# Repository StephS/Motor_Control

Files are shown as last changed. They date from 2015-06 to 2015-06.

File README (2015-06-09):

This board is an H-Bridge DC Motor Controller. The ratings are yet to be determined (requires calculation).
The end goal is to support a 12v 60A Electric Trolling Motor for a boat. This board does NOT have a PWM source (that will be a separate board).
Licence is CC-BY-SA

This board is a PROTOTYPE until the design is built and tested.

The bottom traces need Solid wire soldered on to improve current capacity. Please read the Allegro A3941 Datasheet for usage.

If you'd like to donate so I can buy the full version of Eagle, and make more cool stuff, please contact me through Google+

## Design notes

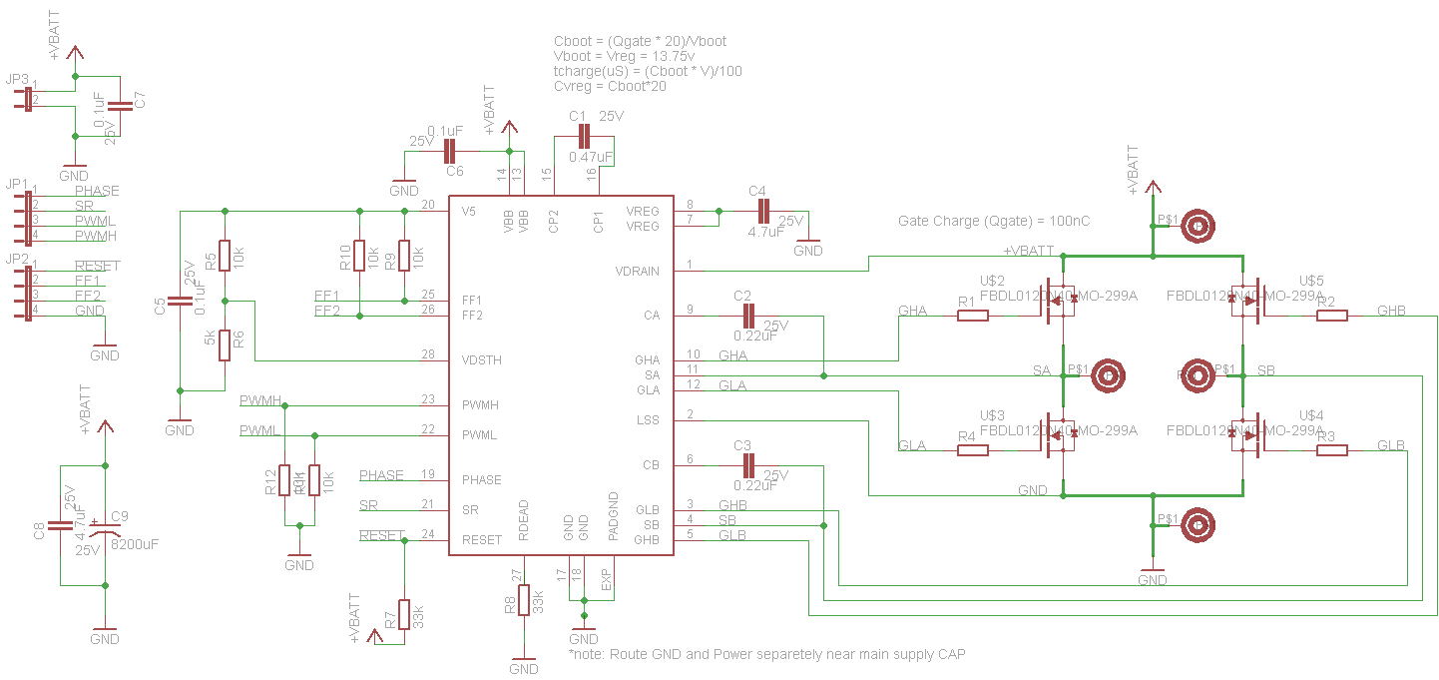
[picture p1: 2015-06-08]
Schematic.png

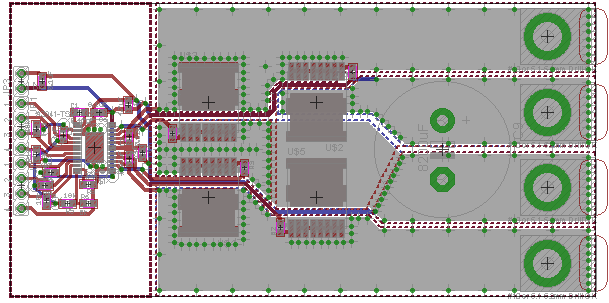
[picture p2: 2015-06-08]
Layout.png

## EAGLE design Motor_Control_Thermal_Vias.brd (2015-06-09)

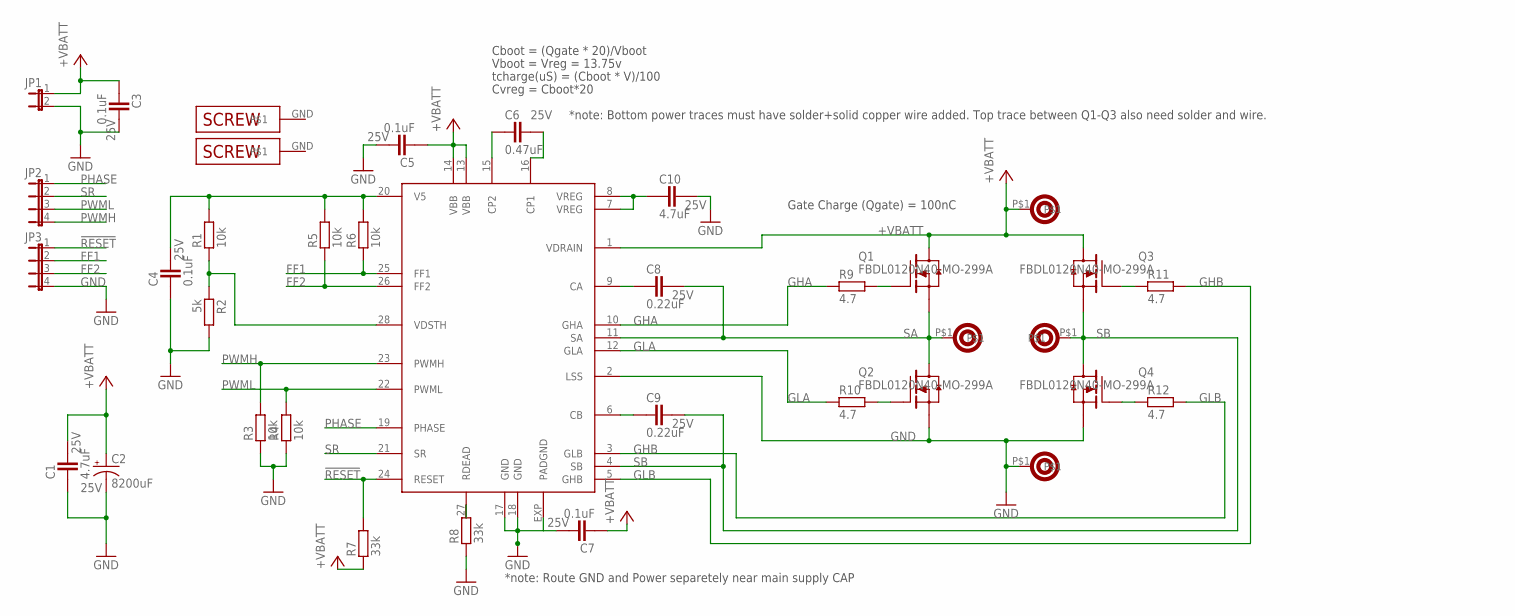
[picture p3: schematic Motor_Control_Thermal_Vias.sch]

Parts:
C1, C10: 4.7uF; CAPC1608X92N; VOLTAGE 25V
C2: 8200uF; CAP-10-22; VOLTAGE 25V
C3, C5, C7: 0.1uF; CAPC1608X92N; VOLTAGE 25V
C4: 0.1uF; CAPC_0603_LONG; VOLTAGE 25V
C6: 0.47uF; CAPC1608X92N; VOLTAGE 25V
C8, C9: 0.22uF; CAPC_0603_LONG; VOLTAGE 25V
J1, J2, J3, J4: 63971-1-QC_TAB-RA; QUICK_CONN_TAB-RA
JP1: JP1E; JP1
JP2, JP3: JP4E; JP4
Q1, Q2, Q3, Q4: FBDL0120N40-MO-299A; MO-299
R1, R3, R4, R5, R6: 10k; RESC1608X55N
R2: 5k; RESC1608X55N
R7, R8: 33k; RESC1608X55N
R9, R10, R11, R12: 4.7; RESC1608X55N
SCREW1, SCREW2: SCREW-4MM; PLATEDSCREW-4MM
U1: A3941-TSSOP28-LP; TSSOP28-LP

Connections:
!RESET: JP3.1, R7.2, U1.24 (RESET)
+VBATT: C1.2, C2.+, C3.1, C5.1, C7.1, J2.P$1, JP1.1, Q1.P$9 (D), Q3.P$9 (D), R7.1, U1.1 (VDRAIN), U1.13 (VBB), U1.14 (VBB)
FF1: JP3.2, R6.1, U1.25 (FF1)
FF2: JP3.3, R5.1, U1.26 (FF2)
GHA: R9.1, U1.10 (GHA)
GHB: R11.2, U1.5 (GHB)
GLA: R10.1, U1.12 (GLA)
GLB: R12.2, U1.3 (GLB)
GND: C1.1, C2.-, C3.2, C4.1, C5.2, C7.2, C10.2, J4.P$1, JP1.2, JP3.4, Q2.P$2 (S), Q2.P$3 (S), Q2.P$4 (S), Q2.P$5 (S), Q2.P$6 (S), Q2.P$7 (S), Q2.P$8 (S), Q4.P$2 (S), Q4.P$3 (S), Q4.P$4 (S), Q4.P$5 (S), Q4.P$6 (S), Q4.P$7 (S), Q4.P$8 (S), R2.2, R3.1, R4.1, R8.1, U1.2 (LSS), U1.17 (GND), U1.18 (GND), U1.EXP (PADGND)
unnamed: Q1.P$1 (G), R9.2
unnamed: Q2.P$1 (G), R10.2
unnamed: Q4.P$1 (G), R12.1
unnamed: Q3.P$1 (G), R11.1
unnamed: C10.1, U1.7 (VREG), U1.8 (VREG)
unnamed: C8.1, U1.9 (CA)
unnamed: R1.1, R2.1, U1.28 (VDSTH)
unnamed: C9.1, U1.6 (CB)
unnamed: R8.2, U1.27 (RDEAD)
unnamed: C6.1, U1.15 (CP2)
unnamed: C6.2, U1.16 (CP1)
PHASE: JP2.1, U1.19 (PHASE)
PWMH: JP2.4, R3.2, U1.23 (PWMH)
PWML: JP2.3, R4.2, U1.22 (PWML)
SA: C8.2, J1.P$1, Q1.P$2 (S), Q1.P$3 (S), Q1.P$4 (S), Q1.P$5 (S), Q1.P$6 (S), Q1.P$7 (S), Q1.P$8 (S), Q2.P$9 (D), U1.11 (SA)
SB: C9.2, J3.P$1, Q3.P$2 (S), Q3.P$3 (S), Q3.P$4 (S), Q3.P$5 (S), Q3.P$6 (S), Q3.P$7 (S), Q3.P$8 (S), Q4.P$9 (D), U1.4 (SB)
SR: JP2.2, U1.21 (SR)
V5: C4.2, R1.2, R5.2, R6.2, U1.20 (V5)

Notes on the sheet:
Cboot = (Qgate * 20)/Vboot
Vboot = Vreg = 13.75v
Gate Charge (Qgate) = 100nC
tcharge(uS) = (Cboot * V)/100
Cvreg = Cboot*20
*note: Route GND and Power separetely near main supply CAP
*note: Bottom power traces must have solder+solid copper wire added. Top trace between Q1-Q3 also need solder and wire.

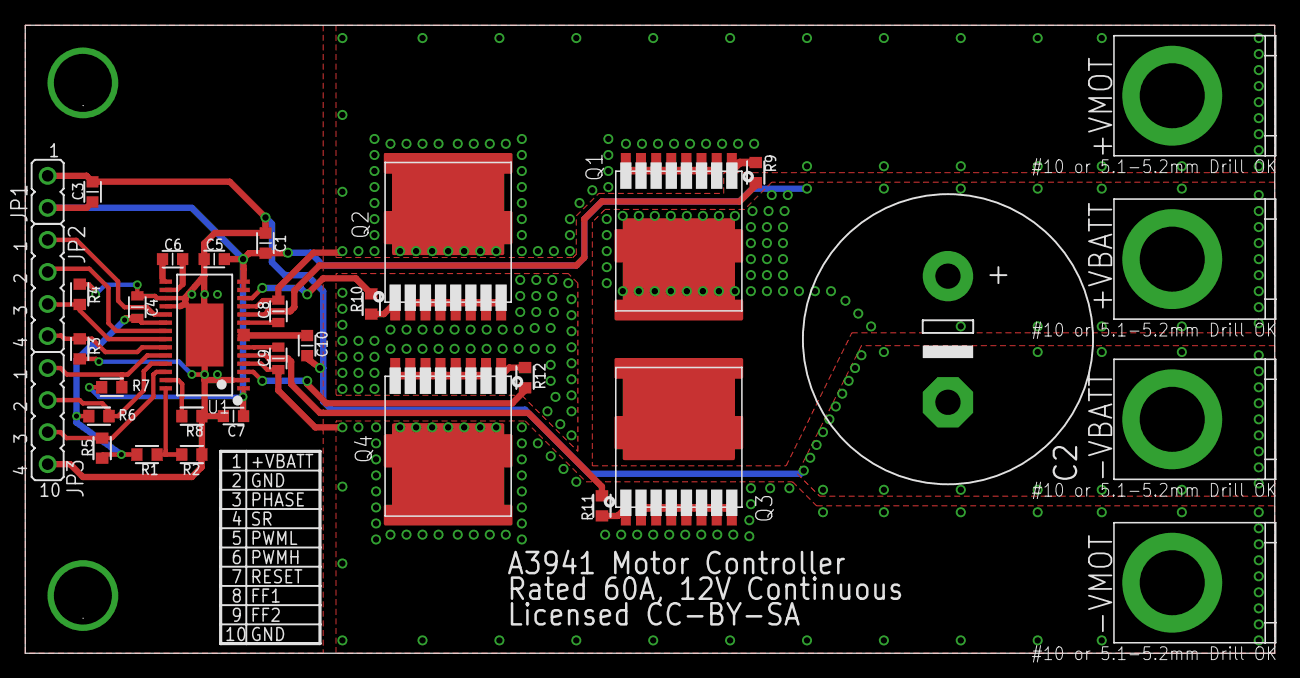
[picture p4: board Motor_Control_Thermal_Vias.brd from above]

Board: 2 copper layers, 99.1 x 49.8 mm, 36 parts (0 on the bottom side), 27 nets.

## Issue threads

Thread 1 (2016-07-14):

Board is tested?

xpix, 2016-07-14:
Hello,

i like your Design of this motor control. After a year i want to know, if the board tested know or it's just a design?

Frank

StephS, 2016-07-23:
Sorry, I have not tested it yet. No funds to make it.

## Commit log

2015-06-08 First board revision.
    The gate resistors need to be calculated. Everything else is fine. (I
    Hope)
    [Motor_Control_no_mask.brd, Motor_Control_no_mask.sch]
2015-06-08 Fixed the solder mask and Gate resistors
    The soldermask on the bottom side has been changed so there is at least
    20 mils covering the traces. this should prevent shorts.
    The gate resistors are now 4.7 Ohm. I'm not 100% sure this is correct,
    might change to 10 Ohm if I see issues.
    [Motor_Control_no_mask.brd, Motor_Control_no_mask.sch]
2015-06-09 More Via's!
    It can't be a bad thing to add more via's to improve thermals. I also
    added another CAP to improve noise. Silkscreen is updated and the board
    is ready for production!
    [Motor_Control_Thermal_Vias.brd, Motor_Control_Thermal_Vias.sch]

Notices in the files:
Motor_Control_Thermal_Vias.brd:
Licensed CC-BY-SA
